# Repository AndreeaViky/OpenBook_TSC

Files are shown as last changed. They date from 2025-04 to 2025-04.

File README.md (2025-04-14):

# OpenBook

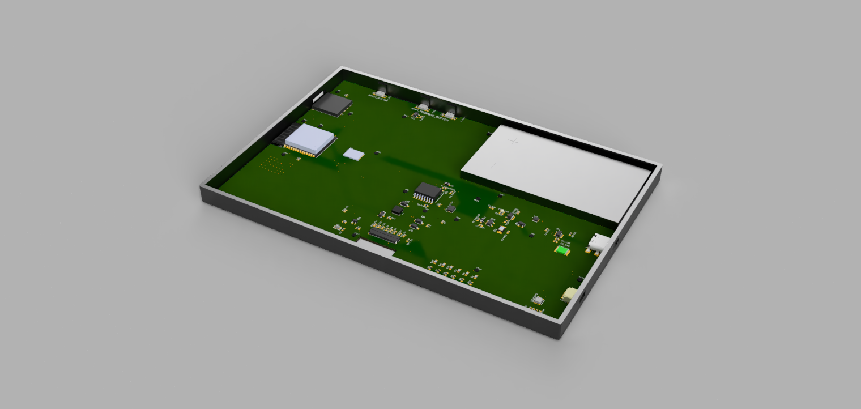
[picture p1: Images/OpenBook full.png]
full_render


## Block Diagram

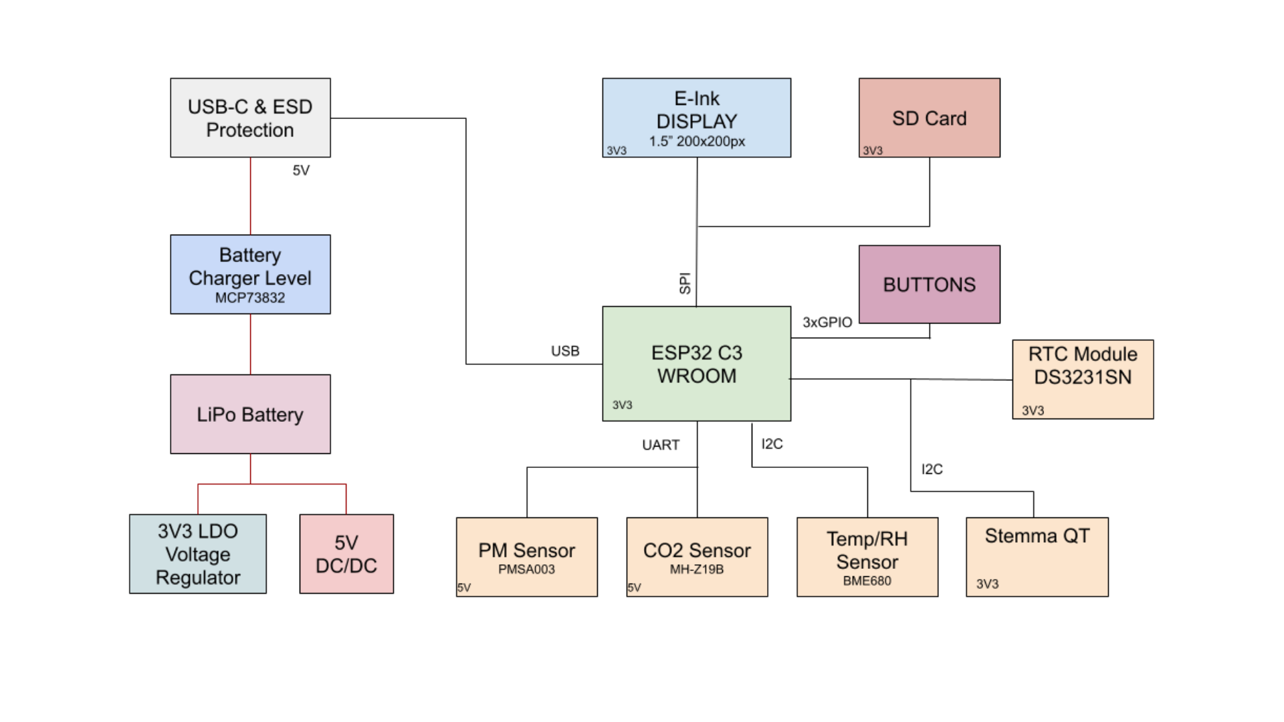
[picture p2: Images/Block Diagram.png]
block_diagram


## Implementation steps

1. Schematic Design

   - The schematic was created based on the provided electrical diagram.
   - Components were added using the DeskAssistant library.
   - An Electrical Rules Check (ERC) was performed to ensure there were no errors or missing connections.

2. PCB Layout

   - The schematic was transferred to the PCB editor using "Switch to PCB."
   - Components were arranged according to the layout reference.
   - The board outline was drawn to the required dimensions, including necessary cutouts.
   - Key components were positioned first for visibility, while resistors and capacitors were placed based on their proximity in the schematic.
   - Auto-routing was performed on both the top and bottom layers using a 0.15 mm trace width.
   - Power traces were manually adjusted to have a minimum width of 0.30 mm for proper current handling.
   - Ground planes were created using the GND signal, followed by via stitching to improve ground continuity.
   - Most stitching vias were placed around the antenna area for enhanced grounding and RF performance.

3. 3D Components

   - 3D models were assigned in the schematic using the [Component Search Engine] (https://componentsearchengine.com).
   - Models were accurately aligned based on their footprints for realistic placement in 3D view.

4. Case Update

   - After placing the PCB inside the enclosure, the case design was modified to accommodate connectors.
   - Adjustments were made to ensure all ports were accessible and properly aligned.

5. Custom 3D Models
   - 3D models for the enclosure and display were created based on technical drawings and datasheets.
   - These models were then placed into the final assembly to verify fit and alignment.

## Bill of Materials (BOM)

| Component | Link | Datasheet |
| --- | --- | --- |
| BME680 | [Model](https://www.snapeda.com/parts/BME680/Bosch/view-part/?welcome=home) | [Datasheet](//efaidnbmnnnibpcajpcglclefindmkaj/https://www.bosch-sensortec.com/media/boschsensortec/downloads/datasheets/bst-bme680-ds001.pdf) |
| BUTTON | [Model](https://industry.panasonic.com/global/en/products/control/switch/light-touch/number/evqpuj02k) | [Datasheet](https://www.lcsc.com/datasheet/lcsc_datasheet_2201121800_PANASONIC-EVQPUJ02K_C2936858.pdf) |
| CAPACITOR | [Model](<https://componentsearchengine.com/part-view/R0402%201%25%20100%20K%20(RC0402FR-07100KL)/YAGEO>) | [Datasheet](//efaidnbmnnnibpcajpcglclefindmkaj/https://www.resistor.com/assets/pdf/0402tstd.pdf) |
| R0402 | [Model](<https://componentsearchengine.com/part-view/R0402%201%25%20100%20K%20(RC0402FR-07100KL)/YAGEO>) | [Datasheet](//efaidnbmnnnibpcajpcglclefindmkaj/https://www.resistor.com/assets/pdf/0402tstd.pdf) |
| CPH3225A | [Model](https://www.snapeda.com/parts/CPH3225A/Seiko+Instruments/view-part/?ref=eda) | [Datasheet](https://octopart.com/datasheet/cph3225a-seiko-25340571) |
| EVQPUJ02K | [Model](https://industry.panasonic.com/global/en/products/control/switch/light-touch/number/evqpuj02k) | [Datasheet](https://www.lcsc.com/datasheet/lcsc_datasheet_2201121800_PANASONIC-EVQPUJ02K_C2936858.pdf) |
| KP-1608SURCK | [Model](https://www.snapeda.com/parts/KP-1608SURCK/Kingbright/view-part/?ref=search&t=LED%200603) | [Datasheet](//efaidnbmnnnibpcajpcglclefindmkaj/https://media.elv.com/file/107153_led_surck1608_data.pdf) |
| USBLC6-2SC6Y | [Model](https://www.snapeda.com/parts/USBLC6-2SC6Y/STMicroelectronics/view-part/?ref=eda) | [Datasheet](https://www.digikey.com/en/htmldatasheets/production/1375342/0/0/1/usblc6-2sc6y) |
| SD0805S020S1R0 | [Model](https://ro.mouser.com/ProductDetail/KYOCERA-AVX/SD0805S020S1R0?qs=jCA%252BPfw4LHbpkAoSnwrdjw%3D%3D) | [Datasheet](https://www.alldatasheet.com/view.jsp?Searchword=SD0805S&sField=2) |
| PGB1010603MR | [Model](https://www.snapeda.com/parts/PGB1010603MR/Littelfuse/view-part/?ref=eda) | [Datasheet](https://www.alldatasheet.com/view.jsp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) |
| BD5229G-TR | [Model](https://componentsearchengine.com/part-view/BD5229G-TR/ROHM%20Semiconductor) | [Datasheet](https://www.lcsc.com/datasheet/lcsc_datasheet_2201131330_ROHM-Semicon-BD5229G-TR_C962636.pdf) |
| XC6220A331MR-G | [Model](https://componentsearchengine.com/part-view/XC6220A331MR-G/Torex) | [Datasheet](https://www.alldatasheet.com/view.jsp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) |
| USB4110-GF-A | [Model](<https://componentsearchengine.com/part-view/USB4110-GF-A/GCT%20(GLOBAL%20CONNECTOR%20TECHNOLOGY)>) | [Datasheet](//efaidnbmnnnibpcajpcglclefindmkaj/https://gct.co/files/drawings/usb4110.pdf) |
| Adafruit LEDCHIP-LED0603 | [Model](https://eu.mouser.com/ProductDetail/Adafruit/4208?qs=PzGy0jfpSMtbScLbr0L5dw%3D%3D) | [Datasheet](https://www.arrow.com/en/manufacturers/adafruit-industries/datasheets) |
| Bobina | [Model](https://store.comet.srl.ro/Catalogue/Product/43497/) | [Datasheet](https://www.scribd.com/document/814581278/Datasheet-Bobina) |
| PFMF | [Model](https://www.mouser.co.uk/ProductDetail/EPCOS-TDK/B72520T0350K062?qs=dEfas%2FXlABIszF52uu7vrg%3D%3D) | [Datasheet](https://ro.mouser.com/c/ds/circuit-protection/thermistors/resettable-fuses-pptc/?m=Schurter&series=PFMF) |
| DMG2305UX-7 | [Model](https://componentsearchengine.com/part-view/DMG2305UX-7/Diodes%20Incorporated) | [Datasheet](//efaidnbmnnnibpcajpcglclefindmkaj/https://www.mouser.com/datasheet/2/115/DMG2305UX-266242.pdf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) |
| Si1308EDL-T1-GE3 | [Model](https://componentsearchengine.com/part-view/SI1308EDL-T1-GE3/Vishay) | [Datasheet](https://www.alldatasheet.com/view.jsp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) |
| MCP73831T-5ACI/OT | [Model](https://www.mouser.co.uk/ProductDetail/Microchip-Technology/MCP73831T-5ACI-OT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) | [Datasheet](//efaidnbmnnnibpcajpcglclefindmkaj/https://ww1.microchip.com/downloads/en/DeviceDoc/MCP73831-Family-Data-Sheet-DS20001984H.pdf) |
| SMD Solder | [Model](https://grabcad.com/library/solder-jumpers-1) | [Datasheet]() |
| W25Q512JVEIQ | [Model](https://www.snapeda.com/parts/ESP32-C6-WROOM-1-N8/Espressif+Systems/view-part/?ref=eda) | [Datasheet](//efaidnbmnnnibpcajpcglclefindmkaj/https://www.mouser.com/datasheet/2/949/W25Q512JV_SPI_RevB_06252019_KMS-2487502.pdf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) |
| ESP32-C6-WROOM-1-N8 | [Model](https://www.snapeda.com/parts/ESP32-C6-WROOM-1-N8/Espressif+Systems/view-part/?ref=eda) | [Datasheet](//efaidnbmnnnibpcajpcglclefindmkaj/https://www.mouser.com/catalog/specsheets/Espressif_ESP32_C6_WROOM_1%20_Datasheet_V0.1_PRELIMINARY_en.pdf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) |
| DS3231SN# | [Model](https://www.snapeda.com/parts/DS3231SN%23/Analog+Devices/view-part/?ref=eda) | [Datasheet](https://www.alldatasheet.com/view.jsp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) |
| MAX17048G+T10 | [Model](https://www.snapeda.com/parts/MAX17048G+T10/Analog+Devices/view-part/?ref=eda) | [Datasheet](https://www.alldatasheet.com/view.jsp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) |

## Hardware Overview

The central unit of the system is the ESP32-C6-WROOM-1-N8, a 32-bit RISC-V microcontroller running at 160 MHz. It manages all processing tasks, communication protocols, and system control. It includes integrated support for Wi-Fi 6 (2.4 GHz) and Bluetooth 5.0, enabling reliable wireless connectivity for IoT applications.

## Power Supply & Battery Management

- Battery: Rechargeable 3.7V 1800mAh Li-Po battery, chosen for its compact size and high energy density.

- Charging Module: Based on the MCP73831T, which provides efficient and safe USB charging (5V input through USB-C).

- Voltage Regulation: A low-dropout (LDO) regulator provides a consistent 3.3V output required by the system components.

- Protections: Integrated safeguards against overcharging and deep discharge ensure long battery life and safe operation.

## Display module

- The device features a 7.5-inch E-Ink display, ideal for low-power, high-contrast applications.

- With a resolution of 800x480 pixels, it delivers sharp, readable content.

- It operates over the SPI bus, offering fast updates while minimizing power usage.

## Storage Solutions

- MicroSD Module: Offers expandable storage using FAT32, communicating via SPI.

- External NOR Flash (64MB): Provides additional non-volatile storage, also interfaced through SPI.

## Connectivity & User Input

- USB-C Port: Serves as both the power input and a communication channel, supported by ESD protection and a Schottky diode for reverse current prevention.

- Tactile Buttons: Provide manual input options for user interaction.

- Interfaces in Use:

  - GPIOs: Used for button input and other control signals

  - SPI: Shared by the SD card, flash memory, and display

  - I2C: Used by environmental sensor and RTC

  - UART: Utilized for debugging and serial monitoring

  - Wi-Fi & Bluetooth: Integrated in the ESP32-C6 for remote communication

## Errors

While editing the PCB in Fusion 360, I encountered the following errors:

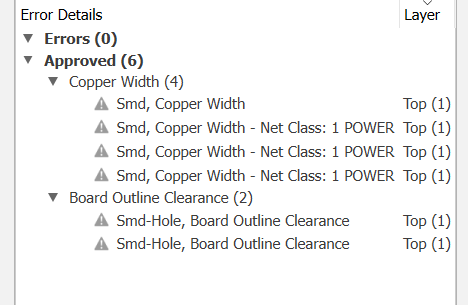
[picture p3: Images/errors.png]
errors


The errors occurred due to the size of the holes in the PCB, so I approved them.

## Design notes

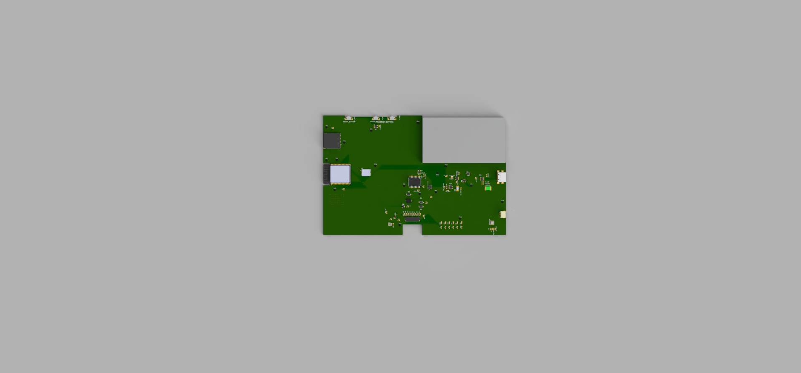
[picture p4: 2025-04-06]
Images/board & charger.png

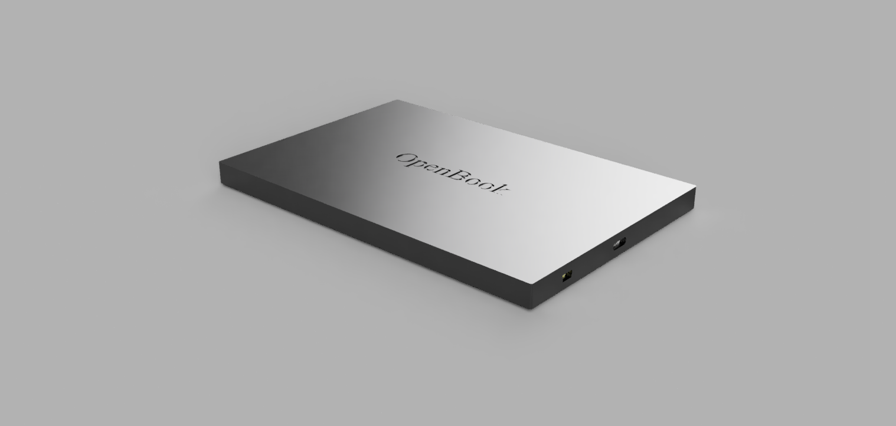
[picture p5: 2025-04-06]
Images/OpenBook Enclosure.png

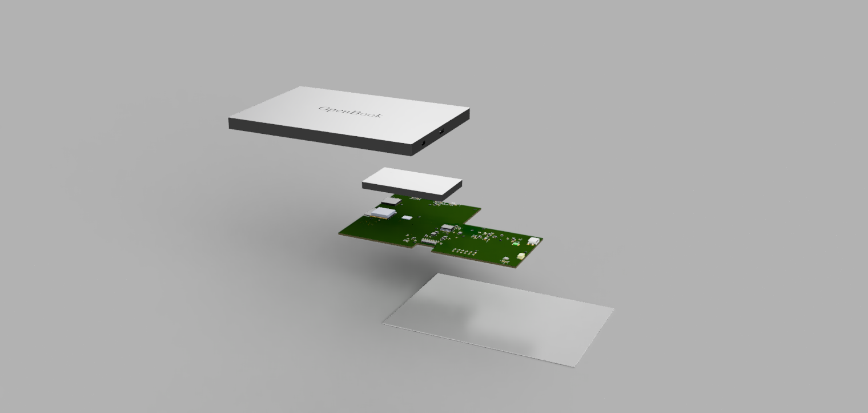
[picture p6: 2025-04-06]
Images/exploded_view.png

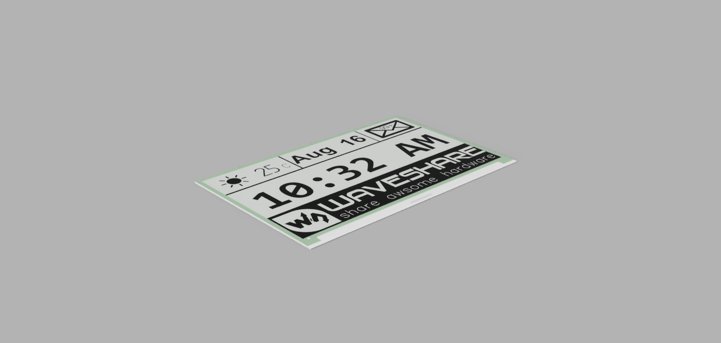
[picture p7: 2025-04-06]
Images/display.png

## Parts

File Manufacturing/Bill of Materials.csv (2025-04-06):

Qty | Value | Device | Package | Parts | Description | ARROW_PART_NUMBER | ARROW_PRICE-STOCK | AVAILABILITY | CENTROID_NOT_SPECIFIED | CHECK_PRICES | COPYRIGHT | DATASHEET | DESCRIPTION | DIGIKEY_DESCRIPTION | DIGIKEY_PART_NUMBER | HEIGHT | LEAD_FREE | MANUFACTURER_NAME | MANUFACTURER_PART_NUMBER | MF | MFR_NAME | MOUSER_PART_NUMBER | MOUSER_PRICE-STOCK | MOUSER_TESTING_PART_NUMBER | MOUSER_TESTING_PRICE-STOCK | MP | MPN | PACKAGE | POPULARITY | PREFIX | PRICE | PROD_ID | PURCHASE-URL | ROHS | SNAPEDA_LINK | SPICEMODEL | SPICEPREFIX | TEMPERATURE_RANGE_HIGH | TEMPERATURE_RANGE_LOW | THERMALLOSS | TP_SIGNAL_NAME | VALUE | LSCS Part Number
1 |  | ADAFRUIT_LEDCHIP-LED0603 | ADAFRUIT_CHIP-LED0603 | CHG_LED | LED |  |  |  |  |  |  |  |  |  |  |  |  |  |  |  |  |  |  |  |  |  |  |  |  |  |  |  |  |  |  |  |  |  |  |  |  |  | https://www.snapeda.com/parts/KP-1608SURCK/Kingbright/view-part/?ref=search&t=LED%200603
1 |  | SJ | SJ | SJ1 | SMD solder JUMPER |  |  |  |  |  |  |  |  |  |  |  |  |  |  |  |  |  |  |  |  |  |  |  | 3 |  |  |  |  |  |  |  |  |  |  |  |  |  | https://grabcad.com/library/solder-jumpers-1
1 | 0.1uF/50V | ESP32_WROVER_EAGLE-LTSPICE_CC0402 | ESP32_WROVER_EAGLE-LTSPICE_C0402 | EPD_C5 | CAPACITOR, European symbol |  |  |  |  |  |  |  |  |  |  |  |  |  |  |  |  |  |  |  |  |  |  |  |  |  |  |  |  |  |  | NONE | C |  |  |  |  |  | https://componentsearchengine.com/part-view/C0402C682K4REC7411/KEMET
1 | 0.47 | ESP32_WROVER_EAGLE-LTSPICE_RR0402 | ESP32_WROVER_EAGLE-LTSPICE_R0402 | R3 | RESISTOR, European symbol |  |  |  |  |  |  |  |  |  |  |  |  |  |  |  |  |  |  |  |  |  |  |  |  |  |  |  |  |  |  | NONE | R |  |  |  |  |  | https://componentsearchengine.com/part-view/R0402%201%25%20100%20K%20(RC0402FR-07100KL)/YAGEO
1 | 100K | ESP32_WROVER_EAGLE-LTSPICE_RR0402 | ESP32_WROVER_EAGLE-LTSPICE_R0402 | R1_PWRUSB | RESISTOR, European symbol |  |  |  |  |  |  |  |  |  |  |  |  |  |  |  |  |  |  |  |  |  |  |  |  |  |  |  |  |  |  | NONE | R |  |  |  |  |  | https://componentsearchengine.com/part-view/R0402%201%25%20100%20K%20(RC0402FR-07100KL)/YAGEO
8 | 100nF | ESP32_WROVER_EAGLE-LTSPICE_CC0402 | ESP32_WROVER_EAGLE-LTSPICE_C0402 | C1, C2, C4_USB, C6, C8, C9, C10, C_DELAY | CAPACITOR, European symbol |  |  |  |  |  |  |  |  |  |  |  |  |  |  |  |  |  |  |  |  |  |  |  |  |  |  |  |  |  |  | NONE | C |  |  |  |  |  | https://componentsearchengine.com/part-view/C0402C682K4REC7411/KEMET
1 | 100uF TANT | RCL_CPOL-EUCT3528 | RCL_CT3528 | C3 | POLARIZED CAPACITOR, European symbol |  |  |  |  |  |  |  |  |  |  |  |  |  |  |  |  |  |  |  |  |  |  |  | 0 |  |  |  |  |  |  |  | C |  |  |  |  |  | https://componentsearchengine.com/part-view/CPH3225A/Seiko%20Semiconductors
16 | 10K | ESP32_WROVER_EAGLE-LTSPICE_RR0402 | ESP32_WROVER_EAGLE-LTSPICE_R0402 | R1, R1_PINH, R1_PINH1, R2-PINH, R2-PINH1, R4, R5, R6, R7, R8, R9, R10, R_BOOT, R_CHANGE, R_CL1, R_RESET | RESISTOR, European symbol |  |  |  |  |  |  |  |  |  |  |  |  |  |  |  |  |  |  |  |  |  |  |  |  |  |  |  |  |  |  | NONE | R |  |  |  |  |  | https://componentsearchengine.com/part-view/R0402%201%25%20100%20K%20(RC0402FR-07100KL)/YAGEO
1 | 10uF | ESP32_WROVER_EAGLE-LTSPICE_CC0402 | ESP32_WROVER_EAGLE-LTSPICE_C0402 | C7 | CAPACITOR, European symbol |  |  |  |  |  |  |  |  |  |  |  |  |  |  |  |  |  |  |  |  |  |  |  |  |  |  |  |  |  |  | NONE | C |  |  |  |  |  | https://componentsearchengine.com/part-view/C0402C682K4REC7411/KEMET
1 | 112A-TAAR-R03_ATTEND | 112A-TAAR-R03_ATTEND | 112ATAARR03ATTEND | J4 | Micro SD Card Socket, Push-Push Type, Top Mount, SMT, H=1.83mm, 10u |  |  |  |  |  |  |  | Micro SD Card Socket | Push-Push Type | Top Mount | SMT | H=1.83mm | 10u |  |  | 1.9mm |  | ATTEND | 112A-TAAR-R03 ATTEND |  |  |  |  |  |  |  |  |  |  |  |  |  |  |  |  |  |  | https://componentsearchengine.com/part-view/112A-TAAR-R03%20ATTEND/ATTEND
1 | 15 | ESP32_WROVER_EAGLE-LTSPICE_RR0402 | ESP32_WROVER_EAGLE-LTSPICE_R0402 | R_CAPACITOR | RESISTOR, European symbol |  |  |  |  |  |  |  |  |  |  |  |  |  |  |  |  |  |  |  |  |  |  |  |  |  |  |  |  |  |  | NONE | R |  |  |  |  |  | https://componentsearchengine.com/part-view/R0402%201%25%20100%20K%20(RC0402FR-07100KL)/YAGEO
1 | 1uF | ESP32_WROVER_EAGLE-LTSPICE_CC0402 | ESP32_WROVER_EAGLE-LTSPICE_C0402 | C5 | CAPACITOR, European symbol |  |  |  |  |  |  |  |  |  |  |  |  |  |  |  |  |  |  |  |  |  |  |  |  |  |  |  |  |  |  | NONE | C |  |  |  |  |  | https://componentsearchengine.com/part-view/C0402C682K4REC7411/KEMET
9 | 1uF/50V | ESP32_WROVER_EAGLE-LTSPICE_CC0402 | ESP32_WROVER_EAGLE-LTSPICE_C0402 | EPD_C1, EPD_C2, EPD_C6, EPD_C7, EPD_C8, EPD_C9, EPD_C10, EPD_C11, EPD_C12 | CAPACITOR, European symbol |  |  |  |  |  |  |  |  |  |  |  |  |  |  |  |  |  |  |  |  |  |  |  |  |  |  |  |  |  |  | NONE | C |  |  |  |  |  | https://componentsearchengine.com/part-view/C0402C682K4REC7411/KEMET
1 | 2.2 | ESP32_WROVER_EAGLE-LTSPICE_RR0402 | ESP32_WROVER_EAGLE-LTSPICE_R0402 | R2 | RESISTOR, European symbol |  |  |  |  |  |  |  |  |  |  |  |  |  |  |  |  |  |  |  |  |  |  |  |  |  |  |  |  |  |  | NONE | R |  |  |  |  |  | https://componentsearchengine.com/part-view/R0402%201%25%20100%20K%20(RC0402FR-07100KL)/YAGEO
1 | 200 | ESP32_WROVER_EAGLE-LTSPICE_RR0402 | ESP32_WROVER_EAGLE-LTSPICE_R0402 | R1_BAT | RESISTOR, European symbol |  |  |  |  |  |  |  |  |  |  |  |  |  |  |  |  |  |  |  |  |  |  |  |  |  |  |  |  |  |  | NONE | R |  |  |  |  |  | https://componentsearchengine.com/part-view/R0402%201%25%20100%20K%20(RC0402FR-07100KL)/YAGEO
1 | 20V/4.2A/52mO/1.4W | ESP32_WROVER_SPARKFUN-DISCRETESEMI_MOSFET_PCH-DMG2305UX-7 | ESP32_WROVER_SPARKFUN-DISCRETESEMI_SOT23-3 | Q1 | P-channel MOSFETs |  |  |  |  |  |  |  |  |  |  |  |  |  |  |  |  |  |  |  |  |  |  |  |  |  |  | TRAN-14388 |  |  |  |  |  |  |  |  |  | 20V/4.2A/52mO/1.4W | https://componentsearchengine.com/part-view/DMG2305UX-7/Diodes%20Incorporated
1 | 20V/4.2A/52mO/1.4W | ESP32_WROVER_SPARKFUN-DISCRETESEMI_MOSFET_PCH-DMG2305UX-7 | ESP32_WROVER_SPARKFUN-DISCRETESEMI_SOT23-3 | Q2 | P-channel MOSFETs |  |  |  |  |  |  |  |  |  |  |  |  |  |  |  |  |  |  |  |  |  |  |  |  |  |  | TRAN-14388 |  |  |  |  |  |  |  | 2305 UX |  | 20V/4.2A/52mO/1.4W | https://componentsearchengine.com/part-view/DMG2305UX-7/Diodes%20Incorporated
1 | 2K | ESP32_WROVER_EAGLE-LTSPICE_RR0402 | ESP32_WROVER_EAGLE-LTSPICE_R0402 | R2_BAT | RESISTOR, European symbol |  |  |  |  |  |  |  |  |  |  |  |  |  |  |  |  |  |  |  |  |  |  |  |  |  |  |  |  |  |  | NONE | R |  |  |  |  |  | https://componentsearchengine.com/part-view/R0402%201%25%20100%20K%20(RC0402FR-07100KL)/YAGEO
5 | 4.7uF | ESP32_WROVER_EAGLE-LTSPICE_CC0402 | ESP32_WROVER_EAGLE-LTSPICE_C0402 | C1_BAT, C1_BAT1, C1_BAT2, C2_BAT, C5_USB | CAPACITOR, European symbol |  |  |  |  |  |  |  |  |  |  |  |  |  |  |  |  |  |  |  |  |  |  |  |  |  |  |  |  |  |  | NONE | C |  |  |  |  |  | https://componentsearchengine.com/part-view/C0402C682K4REC7411/KEMET
1 | 4.7uF/25V | ESP32_WROVER_EAGLE-LTSPICE_CC0402 | ESP32_WROVER_EAGLE-LTSPICE_C0402 | C4 | CAPACITOR, European symbol |  |  |  |  |  |  |  |  |  |  |  |  |  |  |  |  |  |  |  |  |  |  |  |  |  |  |  |  |  |  | NONE | C |  |  |  |  |  | https://componentsearchengine.com/part-view/C0402C682K4REC7411/KEMET
2 | 5k1 | ESP32_WROVER_EAGLE-LTSPICE_RR0402 | ESP32_WROVER_EAGLE-LTSPICE_R0402 | R2-USB, R2-USB1 | RESISTOR, European symbol |  |  |  |  |  |  |  |  |  |  |  |  |  |  |  |  |  |  |  |  |  |  |  |  |  |  |  |  |  |  | NONE | R |  |  |  |  |  | https://componentsearchengine.com/part-view/R0402%201%25%20100%20K%20(RC0402FR-07100KL)/YAGEO
1 | 68uH | 744043680IND_4828-WE-TPC_WRE | IND_4828-WE-TPC_WRE | L1 |  |  |  |  |  |  | Copyright (C) 2024 Ultra Librarian. All rights reserved. |  |  |  |  |  |  |  | 744043680 |  | Wurth Electronics |  |  |  |  |  |  |  |  |  |  |  |  |  |  |  |  |  |  |  |  |  | https://ro.mouser.com/ProductDetail/Wurth-Elektronik/744043680?qs=PGXP4M47uW6VkZq%252BkzjrHA%3D%3D
1 | BD5229G-TR | BD5229G-TR | SOT95P280X125-5N | IC1 | Voltage Detector with Adjustable Delay Time: CMOS processes are utilized to develop high precision, low current consumption CMOS reset ICs that allow arbitrary setting of the delay time. The extensive lineup includes both Nch Open Drain and CMOS output types in a wide range of detection voltages (from 2.3V to 6.0V, in 0.1V steps), enabling selection of the ideal solution based on customer requirements. In addition, the entire series is of course both lead-free and RoHS-compliant. |  |  |  |  |  |  |  | Voltage Detector with Adjustable Delay Time: CMOS processes are utilized to develop high precision | low current consumption CMOS reset ICs that allow arbitrary setting of the delay time. The extensive lineup includes both Nch Open Drain and CMOS output types in a wide range of detection voltages (from 2.3V to 6.0V | in 0.1V steps) | enabling selection of the ideal solution based on customer requirements. In addition | the entire series is of course both lead-free and RoHS-compliant. |  |  | 1.25mm |  | ROHM Semiconductor | BD5229G-TR |  |  | 755-BD5229G-TR | https://www.mouser.co.uk/ProductDetail/ROHM-Semiconductor/BD5229G-TR?qs=4kLU8WoGk0vvnhrrYwdszw%3D%3D |  |  |  |  |  |  |  |  |  |  |  |  |  |  |  | https://componentsearchengine.com/part-view/BD5229G-TR/ROHM%20Semiconductor
1 | BME688 | ESP32_WROVER_BME680_BME680 | ESP32_WROVER_BME680_PSON80P300X300X100-8N | SENSOR2 | Integrated Environmental Unit |  |  | Unavailable |  |  |  |  | Integrated Environmental Unit |  |  |  |  |  |  | Bosch Sensortec |  |  |  |  |  | BME680 |  | LGA-8 Bosch Tools |  |  | None |  |  |  |  |  |  |  |  |  |  |  | https://www.snapeda.com/parts/BME680/Bosch/view-part/?welcome=home
3 | BUTTON_CUSYOMV1 | BUTTON_CUSYOMV1 | MYBUTTON | BOOT_BUTTON, CHANGE_BUTTON, RESET_BUTTON |  |  |  |  |  |  |  |  |  |  |  |  |  |  |  |  |  |  |  |  |  |  |  |  |  |  |  |  |  |  |  |  |  |  |  |  |  |  | https://industry.panasonic.com/global/en/products/control/switch/light-touch/number/evqpuj02k
1 | CPH3225A | CPH3225A | CAPCP3225X100N | C10_SUPERCAP | Cap 0.011F 3.3V 1210 Flat Check availability |  |  | Not in stock |  | https://www.snapeda.com/parts/CPH3225A/Seiko+Instruments/view-part/?ref=eda |  |  | 11 mF (EDLC) Supercapacitor 3.3 V 1210 (3225 Metric) - - |  |  |  |  |  |  | Seiko Instruments |  |  |  |  |  | CPH3225A |  | 1210 Seiko |  |  | None |  | https://www.snapeda.com/api/url_track_click_mouser/?unipart_id=562593&manufacturer=Seiko Instruments&part_name=CPH3225A&search_term=None |  | https://www.snapeda.com/parts/CPH3225A/Seiko+Instruments/view-part/?ref=snap |  |  |  |  |  |  |  | https://www.snapeda.com/parts/CPH3225A/Seiko+Instruments/view-part/?ref=eda
1 | DS3231SN# | DS3231SN# | SOIC127P1032X265-16N | U3 | Real Time Clock Serial 16-Pin SOIC W T/R Check availability |  |  | In Stock |  | https://www.snapeda.com/parts/DS3231SN%23/Analog+Devices/view-part/?ref=eda |  |  | Extremely Accurate I²C-Integrated RTC/TCXO/Crystal |  |  |  |  |  |  | Analog Devices |  |  |  |  |  | DS3231SN# |  | SOIC-16 Maxim |  |  | None |  | https://www.snapeda.com/api/url_track_click_mouser/?unipart_id=99048&manufacturer=Analog Devices&part_name=DS3231SN#&search_term=None |  | https://www.snapeda.com/parts/DS3231SN%23/Analog+Devices/view-part/?ref=snap |  |  |  |  |  |  |  | https://www.snapeda.com/parts/DS3231SN%23/Analog+Devices/view-part/?ref=eda
1 | ESP32-C6-WROOM-1-N8 | ESP32-C6-WROOM-1-N8 | XCVR_ESP32-C6-WROOM-1-N8 | U2 | Check availability |  |  | In Stock |  | https://www.snapeda.com/parts/ESP32-C6-WROOM-1-N8/Espressif+Systems/view-part/?ref=eda |  |  | Multiprotocol Modules ESP32-C6 module | Wi-Fi 6 in 2.4 GHz band | Bluetooth 5 | Zigbee 3.0 and Thread. ESP34-WROOM Compatible - ENGINEERING SAMPLE |  |  |  |  |  |  | Espressif Systems |  |  |  |  |  | ESP32-C6-WROOM-1-N8 |  | None |  |  | None |  |  |  | https://www.snapeda.com/parts/ESP32-C6-WROOM-1-N8/Espressif+Systems/view-part/?ref=snap |  |  |  |  | https://www.snapeda.com/parts/ESP32-C6-WROOM-1-N8/Espressif+Systems/view-part/?ref=eda
1 | ESP32C6_VARISTORCN1812 | ESP32C6_VARISTORCN1812 | ESP32C6_VARISTOR_CT/CN1812 | PFMF.050.1 | VARISTOR |  |  |  |  |  |  |  |  |  |  |  |  |  |  |  |  |  |  |  |  |  |  |  | 0 |  |  |  |  |  |  |  |  |  |  |  |  |  | https://componentsearchengine.com/part-view/PFMF.050.2/SCHURTER
2 | ESP32_WROVER_AVX---SD0805S020S1R0_AVX_SD0805S020S1R0_0_0AVX_SD0805S020S1R0_0_0 | ESP32_WROVER_AVX---SD0805S020S1R0_AVX_SD0805S020S1R0_0_0AVX_SD0805S020S1R0_0_0 | ESP32_WROVER_AVX---SD0805S020S1R0_AVX_SD0805S020S1R0_0 | D2, D7 | Schottky Barrier Rectifier Diode |  |  |  | No |  |  | http://datasheets.avx.com/schottky.pdf |  | DIODE SCHOTTKY 20V 1A 0805 | 478-7800-1-ND |  | yes |  |  | AVX |  | 581-SD0805S020S1R0 |  |  |  |  |  | 0805 (2012 metric) |  | D |  |  |  | yes |  |  |  | +125°C | -55°C |  |  |  | https://ro.mouser.com/ProductDetail/KYOCERA-AVX/SD0805S020S1R0?qs=jCA%252BPfw4LHbpkAoSnwrdjw%3D%3D
1 | ESP32_WROVER_SPARKFUN-IC-POWER_MCP73831 | ESP32_WROVER_SPARKFUN-IC-POWER_MCP73831 | ESP32_WROVER_SPARKFUN-IC-POWER_SOT23-5 | MCP73831 | MCP73831T Li-Ion, Li-Pol Controller |  |  |  |  |  |  |  |  |  |  |  |  |  |  |  |  |  |  |  |  |  |  |  |  |  |  | IC-09995 |  |  |  |  |  |  |  |  |  |  | https://ro.mouser.com/ProductDetail/Microchip-Technology/MCP73831T-5ACI-OT?qs=hH%252BOa0VZEiAcgAcEkuamXg%3D%3D
1 | FH34SRJ-24S-0.5SH_99_ | FH34SRJ-24S-0.5SH_99_ | FH34SRJ24S05SH99 | J1 | (0.50mm) Surface Mount, Right Angle |  |  |  |  |  |  |  | 24 Position FFC | FPC Connector Contacts | (0.50mm) Surface Mount | Right Angle |  |  | 1.1mm |  | Hirose | FH34SRJ-24S-0.5SH(99) |  |  | 798-FH34SRJ24S05SH99 | https://www.mouser.co.uk/ProductDetail/Hirose-Connector/FH34SRJ-24S-0.5SH99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 |  |  |  |  |  |  |  |  |  |  |  |  |  |  |  |  | https://ro.mouser.com/ProductDetail/Hirose-Connector/FH34SRJ-24S-0.5SH99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
1 | MAX17048G+T10 | MAX17048G+T10 | SON50P200X200X80-9N | U4 | Check availability |  |  | In Stock |  | https://www.snapeda.com/parts/MAX17048G+T10/Analog+Devices/view-part/?ref=eda |  |  | 3µA 1-Cell/2-Cell Fuel Gauge with ModelGauge |  |  |  |  |  |  | Analog Devices |  |  |  |  |  | MAX17048G+T10 |  | TDFN-8 Maxim |  |  | None |  | https://www.snapeda.com/api/url_track_click_mouser/?unipart_id=329239&manufacturer=Analog Devices&part_name=MAX17048G+T10&search_term=None |  | https://www.snapeda.com/parts/MAX17048G+T10/Analog+Devices/view-part/?ref=snap |  |  |  |  |  |  |  | https://www.snapeda.com/parts/MAX17048G+T10/Analog+Devices/view-part/?ref=eda
3 | MBR0530 | MBR0530 | SOD3716X135N | D3, D4, D5 | ON SEMICONDUCTOR - MBR0530 - DIODE, SCHOTTKY, 0.5A, 30V, SOD-123 |  |  | In Stock |  | https://www.snapeda.com/parts/MBR0530/Onsemi/view-part/?ref=eda |  |  | Diode Schottky 30 V 500mA Surface Mount SOD-123 |  |  |  |  |  |  | ON Semiconductor |  |  |  |  |  | MBR0530 |  | SOD-123-2 ON Semiconductor |  |  | None |  | https://www.snapeda.com/api/url_track_click_mouser/?unipart_id=179458&manufacturer=ON Semiconductor&part_name=MBR0530&search_term=None |  | https://www.snapeda.com/parts/MBR0530/Onsemi/view-part/?ref=snap |  |  |  |  |  |  |  | https://www.snapeda.com/parts/MBR0530/Onsemi/view-part/?ref=eda
6 | PGB1010603MR | PGB1010603MR | DIOC1608X36N | D6, D8, D9, D10, D11, D12 | Check availability |  |  | In Stock |  | https://www.snapeda.com/parts/PGB1010603MR/Littelfuse/view-part/?ref=eda |  |  | 150V (Typ) Clamp - Ipp Tvs Diode Surface Mount 0603 (1608 Metric) |  |  |  |  |  |  | Littelfuse Inc. |  |  |  |  |  | PGB1010603MR |  | 0603 Littelfuse Inc. |  |  | None |  | https://www.snapeda.com/api/url_track_click_mouser/?unipart_id=5659453&manufacturer=Littelfuse Inc.&part_name=PGB1010603MR&search_term=None |  | https://www.snapeda.com/parts/PGB1010603MR/Littelfuse/view-part/?ref=snap |  |  |  |  |  |  |  | https://componentsearchengine.com/part-view/PGB1010603MR/LITTELFUSE
1 | QWIIC_RIGHT_ANGLE | QWIIC_CONNECTORJS-1MM | JST04_1MM_RA | J3 | SparkFun I2C Standard Qwiic Connector |  |  |  |  |  |  |  |  |  |  |  |  |  |  |  |  |  |  |  |  |  |  |  |  |  |  | CONN-13694 |  |  |  |  |  |  |  |  |  | QWIIC_RIGHT_ANGLE | https://componentsearchengine.com/part-view/PRT-14417/SparkFun
1 | SAMACSYS_PARTS_USB4110-GF-A | SAMACSYS_PARTS_USB4110-GF-A | SAMACSYS_PARTS_USB4110GFA | J2 | CONN USB 2.0 TYPE-C R/A SMT |  |  |  |  |  |  |  | CONN USB 2.0 TYPE-C R/A SMT |  |  | 3.26mm |  | GCT (GLOBAL CONNECTOR TECHNOLOGY) | USB4110-GF-A |  |  | 640-USB4110-GF-A | https://www.mouser.co.uk/ProductDetail/GCT/USB4110-GF-A?qs=KUoIvG%2F9IlYiZvIXQjyJeA%3D%3D |  |  |  |  |  |  |  |  |  |  |  |  |  |  |  |  |  |  |  | https://ro.mouser.com/ProductDetail/GCT/USB4110-GF-A?qs=KUoIvG%2F9IlYiZvIXQjyJeA%3D%3D
1 | SI1308EDL-T1-GE3 | SI1308EDL-T1-GE3 | SOT65P210X110-3N | Q3 | MOSFET N-Ch 30V 1.5A TrenchFET SC70 Vishay Si1308EDL-T1-GE3 N-channel MOSFET Transistor, 1.5 A, 30 V, 3-Pin SC-70 |  |  | In Stock |  | https://www.snapeda.com/parts/SI1308EDL-T1-GE3/Vishay+Siliconix/view-part/?ref=eda |  |  | Si1308EDL-T1-GE3 N-channel MOSFET Transistor | 1.5 A | 30 V | 3-Pin SC-70 | Siliconix / Vishay SI1308EDL-T1-GE3 |  |  |  |  |  |  | Vishay Siliconix |  |  |  |  |  | SI1308EDL-T1-GE3 |  | SOT-323 Vishay Semiconductor |  |  | None |  | https://www.snapeda.com/api/url_track_click_mouser/?unipart_id=274603&manufacturer=Vishay Siliconix&part_name=SI1308EDL-T1-GE3&search_term=None |  | https://www.snapeda.com/parts/SI1308EDL-T1-GE3/Vishay+Siliconix/view-part/?ref=snap |  |  |  |  | https://www.snapeda.com/parts/SI1308EDL-T1-GE3/Vishay+Siliconix/view-part/?ref=eda
17 | TPTP20R | TPTP20R | TP20R | TP1, TP2, TP3, TP4, TP5, TP6, TP7, TP8, TP9, TP10, TP11, TP12, TP13, TP14, TP15, TP16, TP17 | Test pad |  |  |  |  |  |  |  |  |  |  |  |  |  |  |  |  |  |  |  |  |  |  |  | 2
1 | USBLC6-2SC6Y | USBLC6-2SC6Y | SOT95P280X145-6N | D1 | Low Cap. ESD Protection Auto SOT-23-6 STMicroelectronics USBLC6-2SC6Y, Dual Uni-Directional TVS Diode Array, 6-Pin SOT-23 |  |  | In Stock |  | https://www.snapeda.com/parts/USBLC6-2SC6Y/STMicroelectronics/view-part/?ref=eda |  |  | 17V Clamp 5A (8/20µs) Ipp Tvs Diode Surface Mount SOT-23-6 |  |  |  |  |  |  | STMicroelectronics |  |  |  |  |  | USBLC6-2SC6Y |  | SOT-23-6 STMicroelectronics |  |  | None |  |  |  | https://www.snapeda.com/parts/USBLC6-2SC6Y/STMicroelectronics/view-part/?ref=snap |  |  |  |  |  |  |  | https://www.snapeda.com/parts/USBLC6-2SC6Y/STMicroelectronics/view-part/?ref=eda
1 | W25Q512JVEIQ | W25Q512JVEIQ | SON127P600X800X80-9N | U1 | Check availability |  |  | In Stock |  | https://www.snapeda.com/parts/W25Q512JVEIQ/Winbond+Electronics/view-part/?ref=eda |  |  | FLASH - NOR Memory IC 512Mb (64M x 8) SPI - Quad I/O 133 MHz 8-WSON (8x6) |  |  |  |  |  |  | Winbond Electronics |  |  |  |  |  | W25Q512JVEIQ |  | Package |  |  | None |  |  |  | https://www.snapeda.com/parts/W25Q512JVEIQ/Winbond+Electronics/view-part/?ref=snap |  |  |  |  |  |  |  | https://www.snapeda.com/parts/W25Q512JVEIQ/Winbond+Electronics/view-part/?ref=eda
1 | XC6220A331MR-G | XC6220A331MR-G | SOT95P280X120-5N | IC4 | LDO Voltage Regulators |  |  |  |  |  |  |  | LDO Voltage Regulators |  |  | 1.2mm |  | Torex | XC6220A331MR-G |  |  | 865-XC6220A331MR-G | https://www.mouser.co.uk/ProductDetail/Torex-Semiconductor/XC6220A331MR-G?qs=AsjdqWjXhJ8ZSWznL1J0gg%3D%3D |  |  |  |  |  |  |  |  |  |  |  |  |  |  |  |  |  |  |  | https://ro.mouser.com/ProductDetail/Torex-Semiconductor/XC6220A331MR-G?qs=AsjdqWjXhJ8ZSWznL1J0gg%3D%3D

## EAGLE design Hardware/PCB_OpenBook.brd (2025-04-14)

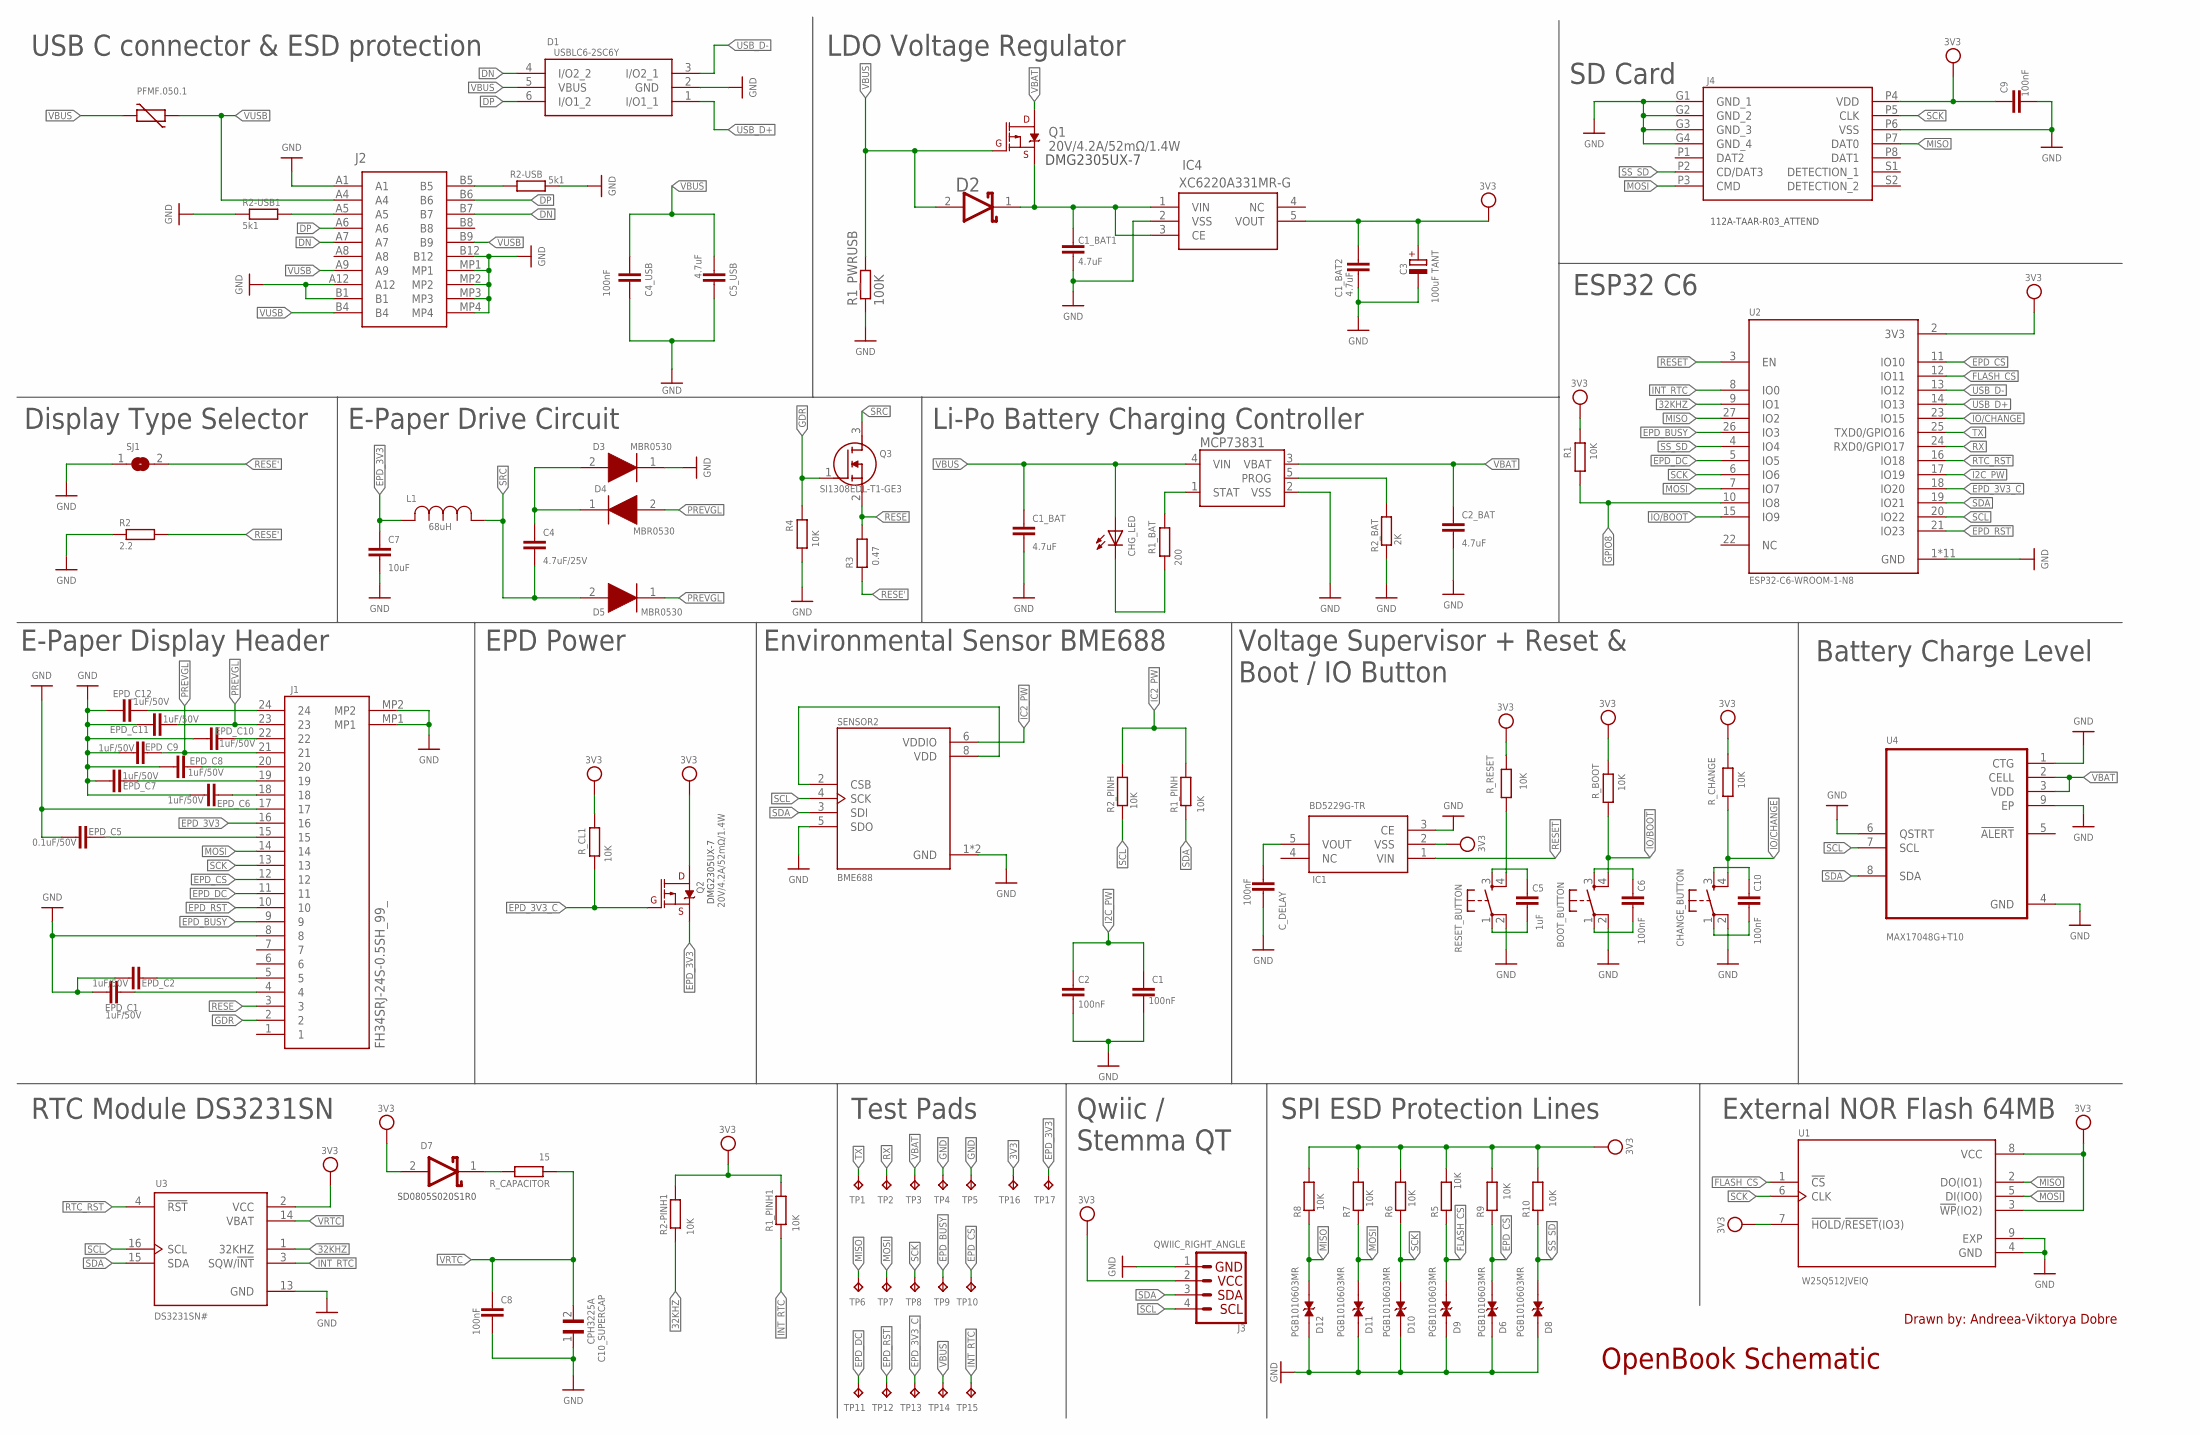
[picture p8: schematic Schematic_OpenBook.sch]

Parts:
BOOT_BUTTON: BUTTON_CUSYOMV1; MYBUTTON
C1, C2, C4_USB, C6, C8, C9, C10: 100nF; ESP32_WROVER_EAGLE-LTSPICE_C0402
C1_BAT, C1_BAT1, C1_BAT2, C2_BAT, C5_USB: 4.7uF; ESP32_WROVER_EAGLE-LTSPICE_C0402
C3: 100uF TANT; RCL_CT3528
C4: 4.7uF/25V; ESP32_WROVER_EAGLE-LTSPICE_C0402
C5: 1uF; ESP32_WROVER_EAGLE-LTSPICE_C0402
C7: 10uF; ESP32_WROVER_EAGLE-LTSPICE_C0402
C10_SUPERCAP: CPH3225A; CAPCP3225X100N
CHANGE_BUTTON: BUTTON_CUSYOMV1; MYBUTTON
CHG_LED: ADAFRUIT_LEDCHIP-LED0603; ADAFRUIT_CHIP-LED0603
C_DELAY: 100nF; ESP32_WROVER_EAGLE-LTSPICE_C0402
D1: USBLC6-2SC6Y; SOT95P280X145-6N
D2, D7: ESP32_WROVER_AVX---SD0805S020S1R0_AVX_SD0805S020S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; ESP32_WROVER_AVX---SD0805S020S1R0_AVX_SD0805S020S1R0_0
D3, D4, D5: MBR0530; SOD3716X135N
D6, D8, D9, D10, D11, D12: PGB1010603MR; DIOC1608X36N
EPD_C1, EPD_C2, EPD_C6, EPD_C7, EPD_C8, EPD_C9, EPD_C10, EPD_C11, EPD_C12: 1uF/50V; ESP32_WROVER_EAGLE-LTSPICE_C0402
EPD_C5: 0.1uF/50V; ESP32_WROVER_EAGLE-LTSPICE_C0402
IC1: XC6220A331MR-G; SOT95P280X120-5N; MANUFACTURER_PART_NUMBER BD5229G-TR
IC4: XC6220A331MR-G; SOT95P280X120-5N
J1: FH34SRJ-24S-0.5SH_99_; FH34SRJ24S05SH99
J2: SAMACSYS_PARTS_USB4110-GF-A; SAMACSYS_PARTS_USB4110GFA
J3: QWIIC_RIGHT_ANGLE; JST04_1MM_RA
J4: 112A-TAAR-R03_ATTEND; 112ATAARR03ATTEND
L1: 68uH; IND_4828-WE-TPC_WRE
MCP73831: ESP32_WROVER_SPARKFUN-IC-POWER_MCP73831; ESP32_WROVER_SPARKFUN-IC-POWER_SOT23-5
PFMF.050.1: ESP32C6_VARISTORCN1812; ESP32C6_VARISTOR_CT/CN1812
Q1, Q2: 20V/4.2A/52mΩ/1.4W; ESP32_WROVER_SPARKFUN-DISCRETESEMI_SOT23-3
Q3: SI1308EDL-T1-GE3; SOT65P210X110-3N
R1, R1_PINH, R1_PINH1, R2-PINH1, R2_PINH, R4, R5, R6, R7, R8, R9, R10: 10K; ESP32_WROVER_EAGLE-LTSPICE_R0402
R1_BAT: 200; ESP32_WROVER_EAGLE-LTSPICE_R0402
R1_PWRUSB: 100K; ESP32_WROVER_EAGLE-LTSPICE_R0402
R2: 2.2; ESP32_WROVER_EAGLE-LTSPICE_R0402
R2-USB, R2-USB1: 5k1; ESP32_WROVER_EAGLE-LTSPICE_R0402
R2_BAT: 2K; ESP32_WROVER_EAGLE-LTSPICE_R0402
R3: 0.47; ESP32_WROVER_EAGLE-LTSPICE_R0402
RESET_BUTTON: BUTTON_CUSYOMV1; MYBUTTON
R_BOOT: 10K; ESP32_WROVER_EAGLE-LTSPICE_R0402
R_CAPACITOR: 15; ESP32_WROVER_EAGLE-LTSPICE_R0402
R_CHANGE: 10K; ESP32_WROVER_EAGLE-LTSPICE_R0402
R_CL1: 10K; ESP32_WROVER_EAGLE-LTSPICE_R0402
R_RESET: 10K; ESP32_WROVER_EAGLE-LTSPICE_R0402
SENSOR2: BME688; ESP32_WROVER_BME680_PSON80P300X300X100-8N
SJ1: SJ
TP1, TP2, TP3, TP4, TP5, TP6, TP7, TP8, TP9, TP10, TP11, TP12, TP13, TP14, TP15, TP16, TP17: TPTP20R; TP20R
U1: W25Q512JVEIQ; SON127P600X800X80-9N
U2: ESP32-C6-WROOM-1-N8; XCVR_ESP32-C6-WROOM-1-N8
U3: DS3231SN#; SOIC127P1032X265-16N
U4: MAX17048G+T10; SON50P200X200X80-9N

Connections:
3V3: C1_BAT2.1, C3.+, C9.1, D7.2 (ANODE), IC1.2 (VSS), IC4.5 (VOUT), J3.2, J4.P4 (VDD), Q2.3 (D), R1.1, R1_PINH1.2, R2-PINH1.2, R5.2, R6.2, R7.2, R8.2, R9.2, R10.2, R_BOOT.1, R_CHANGE.1, R_CL1.1, R_RESET.1, TP16.TP, U1.3 (!WP!(IO2)), U1.7 (!HOLD!/!RESET!(IO3)), U1.8 (VCC), U2.2 (3V3), U3.2 (VCC)
32KHZ: R2-PINH1.1, U2.9 (IO1), U3.1 (32KHZ)
DN: D1.4 (I/O2_2), J2.A7, J2.B7
DP: D1.6 (I/O1_2), J2.A6, J2.B6
EPD_3V3: C7.1, J1.16, L1.2, Q2.2 (S), TP17.TP
EPD_3V3_C: Q2.1 (G), R_CL1.2, TP13.TP, U2.18 (IO20)
EPD_BUSY: J1.9, TP9.TP, U2.26 (IO3)
EPD_CS: D6.2, J1.12, R9.1, TP10.TP, U2.11 (IO10)
EPD_DC: J1.11, TP11.TP, U2.5 (IO5)
EPD_RST: J1.10, TP12.TP, U2.21 (IO23)
FLASH_CS: D9.2, R5.1, U1.1 (!CS), U2.12 (IO11)
GDR: J1.2, Q3.1 (G), R4.1
GND: BOOT_BUTTON.2, C1.2, C1_BAT.2, C1_BAT1.2, C1_BAT2.2, C2.2, C2_BAT.2, C3.-, C4_USB.2, C5_USB.2, C7.2, C8.2, C9.2, C10_SUPERCAP.1, CHANGE_BUTTON.2, C_DELAY.2, D1.2 (GND), D3.1 (K), D6.1, D8.1, D9.1, D10.1, D11.1, D12.1, EPD_C1.2, EPD_C2.2, EPD_C5.2, EPD_C6.2, EPD_C7.2, EPD_C8.2, EPD_C9.2, EPD_C10.2, EPD_C11.2, EPD_C12.2, IC1.3 (CE), IC4.2 (VSS), J1.8, J1.17, J1.MP1, J1.MP2, J2.A1, J2.A12, J2.B1, J2.B12, J2.MP1, J2.MP2, J2.MP3, J2.MP4, J3.1, J4.G1 (GND_1), J4.G2 (GND_2), J4.G3 (GND_3), J4.G4 (GND_4), J4.P6 (VSS), MCP73831.2 (VSS), R1_PWRUSB.1, R2.1, R2-USB.2, R2-USB1.1, R2_BAT.1, R4.2, RESET_BUTTON.2, SENSOR2.1 (GND), SENSOR2.5 (SDO), SENSOR2.7 (GND), SJ1.1, TP4.TP, TP5.TP, U1.4 (GND), U1.9 (EXP), U2.1 (GND), U2.28 (GND), U2.29_1 (GND), U2.29_2 (GND), U2.29_3 (GND), U2.29_4 (GND), U2.29_5 (GND), U2.29_6 (GND), U2.29_7 (GND), U2.29_8 (GND), U2.29_9 (GND), U3.13 (GND), U4.1 (CTG), U4.4 (GND), U4.6 (QSTRT), U4.9 (EP)
GPIO8: R1.2, U2.10 (IO8)
I2C_PW: C1.1, C2.1, U2.17 (IO19)
IC2_PW: R1_PINH.2, R2_PINH.2, SENSOR2.6 (VDDIO)
INT_RTC: R1_PINH1.1, TP15.TP, U2.8 (IO0), U3.3 (SQW/!INT)
IO/BOOT: BOOT_BUTTON.4, R_BOOT.2, U2.15 (IO9)
IO/CHANGE: CHANGE_BUTTON.4, R_CHANGE.2, U2.23 (IO15)
MISO: D12.2, J4.P7 (DAT0), R8.1, TP6.TP, U1.2 (DO(IO1)), U2.27 (IO2)
MOSI: D11.2, J1.14, J4.P3 (CMD), R7.1, TP7.TP, U1.5 (DI(IO0)), U2.7 (IO7)
unnamed: J2.B5, R2-USB.1
unnamed: J2.A5, R2-USB1.2
unnamed: C1_BAT1.1, D2.1 (CATHODE), IC4.1 (VIN), IC4.3 (CE), Q1.2 (S)
unnamed: C10.1, CHANGE_BUTTON.3
unnamed: C4.1, D3.2 (A), D4.1 (K)
unnamed: C10.2, CHANGE_BUTTON.1
unnamed: SENSOR2.2 (CSB), SENSOR2.8 (VDD)
unnamed: MCP73831.5 (PROG), R2_BAT.2
unnamed: EPD_C12.1, J1.24
unnamed: MCP73831.1 (STAT), R1_BAT.1
unnamed: CHG_LED.C, R1_BAT.2
unnamed: C_DELAY.1, IC1.5 (VOUT)
unnamed: EPD_C10.1, J1.22
unnamed: D7.1 (CATHODE), R_CAPACITOR.2
unnamed: EPD_C8.1, J1.20
unnamed: EPD_C7.1, J1.19
unnamed: EPD_C1.1, J1.4
unnamed: RESET_BUTTON.4, R_RESET.2
unnamed: EPD_C6.1, J1.18
unnamed: EPD_C2.1, J1.5
unnamed: EPD_C5.1, J1.15
unnamed: BOOT_BUTTON.1, C6.2
unnamed: C5.2, RESET_BUTTON.1
unnamed: BOOT_BUTTON.3, C6.1
unnamed: C5.1, RESET_BUTTON.3
PREVGL: D4.2 (A), D5.1 (K), EPD_C9.1, EPD_C11.1, J1.21, J1.23
RESE: J1.3, Q3.2 (S), R3.1
RESE': R2.2, R3.2, SJ1.2
RESET: IC1.1 (VIN), U2.3 (EN)
RTC_RST: U2.16 (IO18), U3.4 (!RST)
RX: TP2.TP, U2.24 (RXD0/GPIO17)
SCK: D10.2, J1.13, J4.P5 (CLK), R6.1, TP8.TP, U1.6 (CLK), U2.6 (IO6)
SCL: J3.4, R2_PINH.1, SENSOR2.4 (SCK), U2.20 (IO22), U3.16 (SCL), U4.7 (SCL)
SDA: J3.3, R1_PINH.1, SENSOR2.3 (SDI), U2.19 (IO21), U3.15 (SDA), U4.8 (SDA)
SRC: C4.2, D5.2 (A), L1.1, Q3.3 (D)
SS_SD: D8.2, J4.P2 (CD/DAT3), R10.1, U2.4 (IO4)
TX: TP1.TP, U2.25 (TXD0/GPIO16)
USB_D+: D1.1 (I/O1_1), U2.14 (IO13)
USB_D-: D1.3 (I/O2_1), U2.13 (IO12)
VBAT: C2_BAT.1, MCP73831.3 (VBAT), Q1.3 (D), TP3.TP, U4.2 (CELL), U4.3 (VDD)
VBUS: C1_BAT.1, C4_USB.1, C5_USB.1, CHG_LED.A, D1.5 (VBUS), D2.2 (ANODE), MCP73831.4 (VIN), PFMF.050.1.2, Q1.1 (G), R1_PWRUSB.2, TP14.TP
VRTC: C8.1, C10_SUPERCAP.2, R_CAPACITOR.1, U3.14 (VBAT)
VUSB: J2.A4, J2.A9, J2.B4, J2.B9, PFMF.050.1.1

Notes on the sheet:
USB C connector & ESD protection
LDO Voltage Regulator
DMG2305UX-7
SD Card
112A-TAAR-R03_ATTEND
Display Type Selector
Battery Charge Level
External NOR Flash 64MB
SPI ESD Protection Lines
RTC Module DS3231SN
Test Pads
Qwiic / Stemma QT
E-Paper Drive Circuit
Li-Po Battery Charging Controller
ESP32 C6
E-Paper Display Header
EPD Power
Environmental Sensor BME688
Voltage Supervisor + Reset & Boot / IO Button
SD0805S020S1R0
OpenBook Schematic
Drawn by: Andreea-Viktorya Dobre

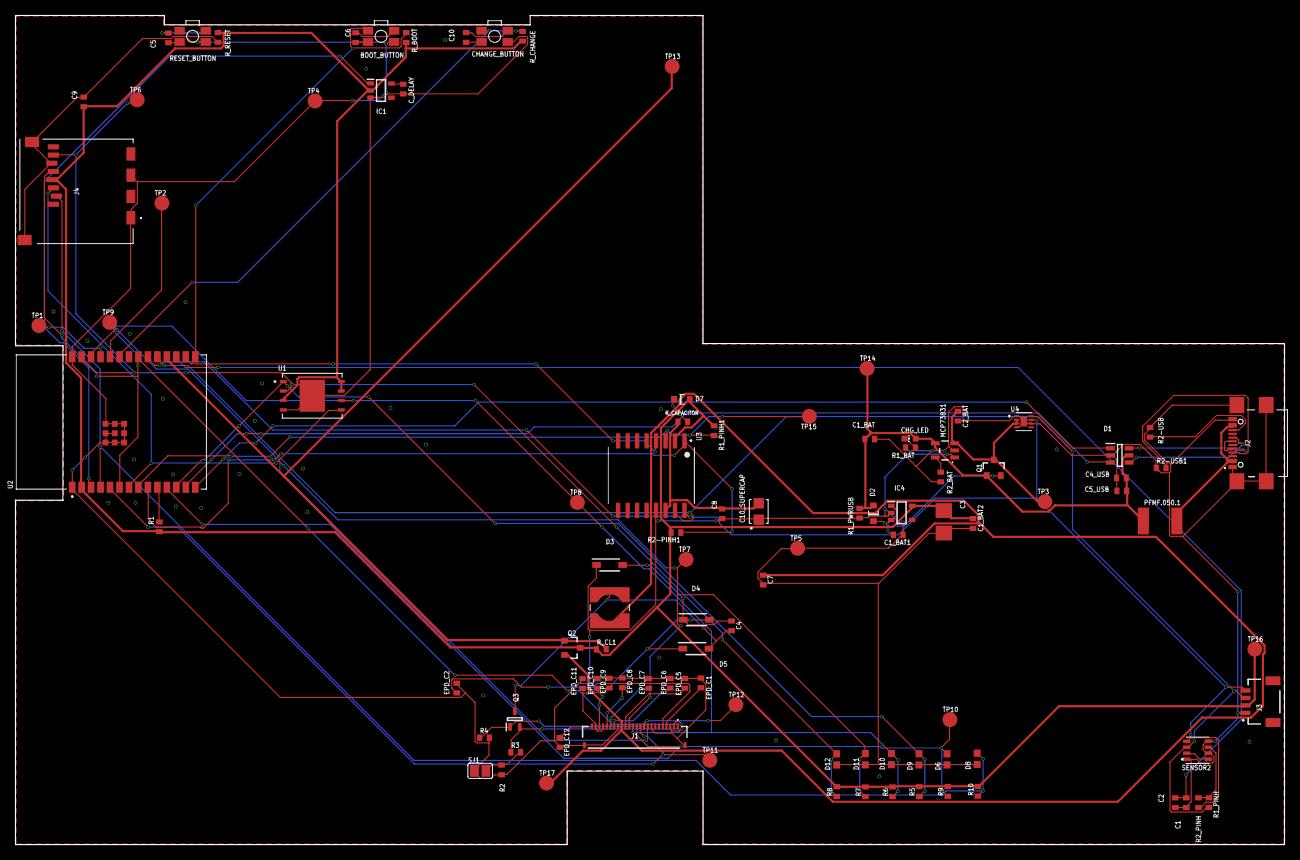
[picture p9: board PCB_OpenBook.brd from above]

Board: 2 copper layers, 170.2 x 111.2 mm, 103 parts (0 on the bottom side), 64 nets.

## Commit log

2025-04-06 Initial commit.
    [Bill of Materials.csv, Board_OpenBook.brd, Pick and Place.csv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]
2025-04-11 Update schematic, reversing component pins
    [Schematic_OpenBook.sch]
2025-04-11 Update PCB
    [PCB_OpenBook.brd]

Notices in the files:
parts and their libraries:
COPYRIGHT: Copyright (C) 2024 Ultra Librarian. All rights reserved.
